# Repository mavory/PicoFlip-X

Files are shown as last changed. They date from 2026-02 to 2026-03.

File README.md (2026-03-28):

<div align="center">
  
# PicoFlip X 
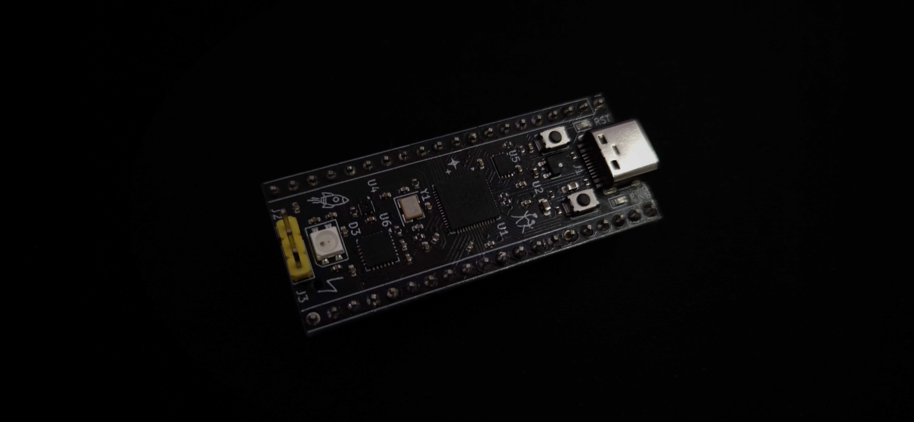
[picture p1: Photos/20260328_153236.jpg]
header


PicoFlip X is a compact RP2040 development board with a built-in IMU for motion tracking, there's also a humidity and temperature sensor! It has several status LEDs, buttons,...
</div>

## Key Features

- DevBoard powered by RP2040 chip
- Humidity and temperature sensor built right on the PCB
- 2 LEDs for visual feedback (PWR and RST)
- IMU - MPU 6050 to monitor the board's current position, all built-in
- USB-C connectivity
- 2-layer PCB, so it's cost-effective to manufacture!
- Modified GPIO pin layout and added one extra +3V3
- Custom silkscreen with images and descriptions

## Why I made this project?

When I finished my last project, I was thinking again about what I could do... I thought I'd try something hard and test my nerves... 💀
So I was looking and came up with this project - DEVBOARD!!

## Schema and PCB
  <div align="center">
    
Here is the circuit diagram!

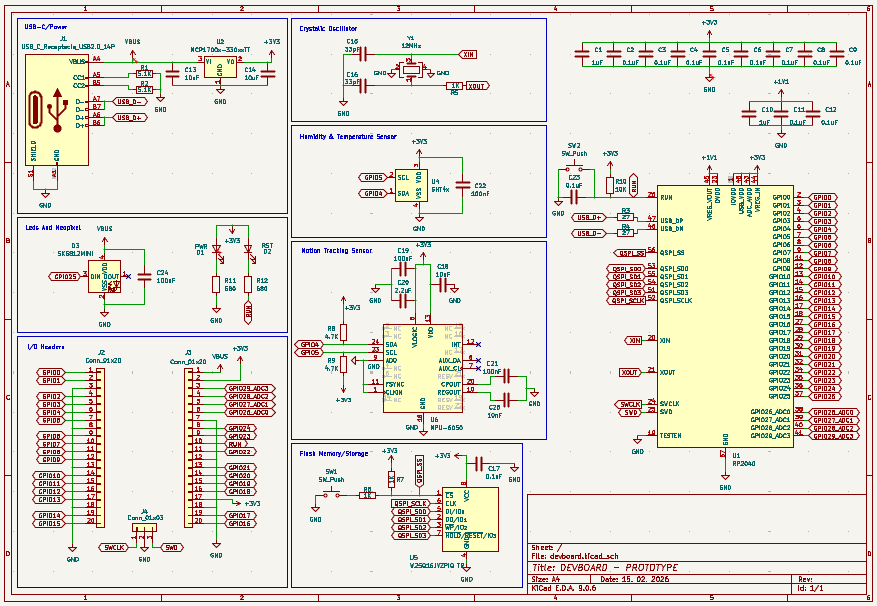
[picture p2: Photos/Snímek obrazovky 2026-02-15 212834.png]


Next, here is the PCB that is created in KiCad:
<div align="center">
  
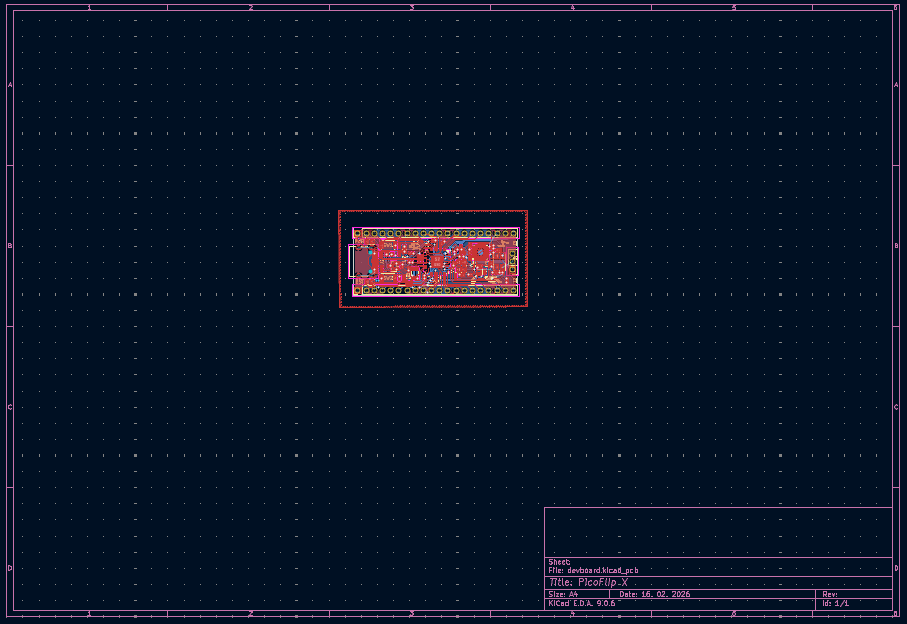
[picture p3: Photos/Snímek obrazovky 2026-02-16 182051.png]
PCB Design

  
</div></div>

## The Design :)
  <div align="center">
    
Here is the top side of the PCB:

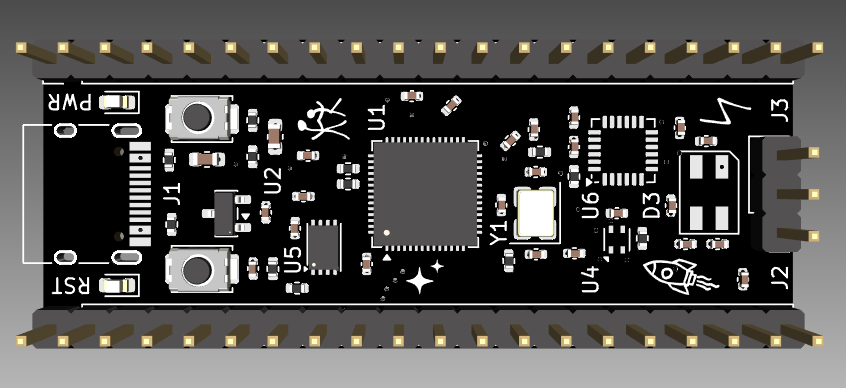
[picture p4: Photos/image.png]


Also here is the bottom of the PCB!
<div align="center">
  
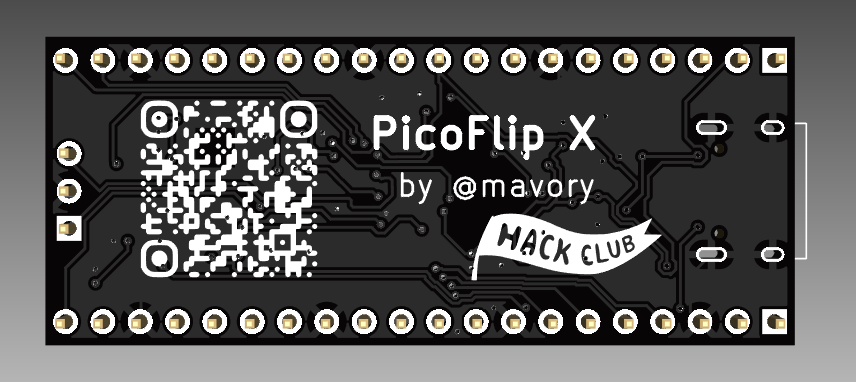
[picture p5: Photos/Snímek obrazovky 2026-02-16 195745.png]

  
</div></div>

## JLCPCB Order
<div align="center">
  
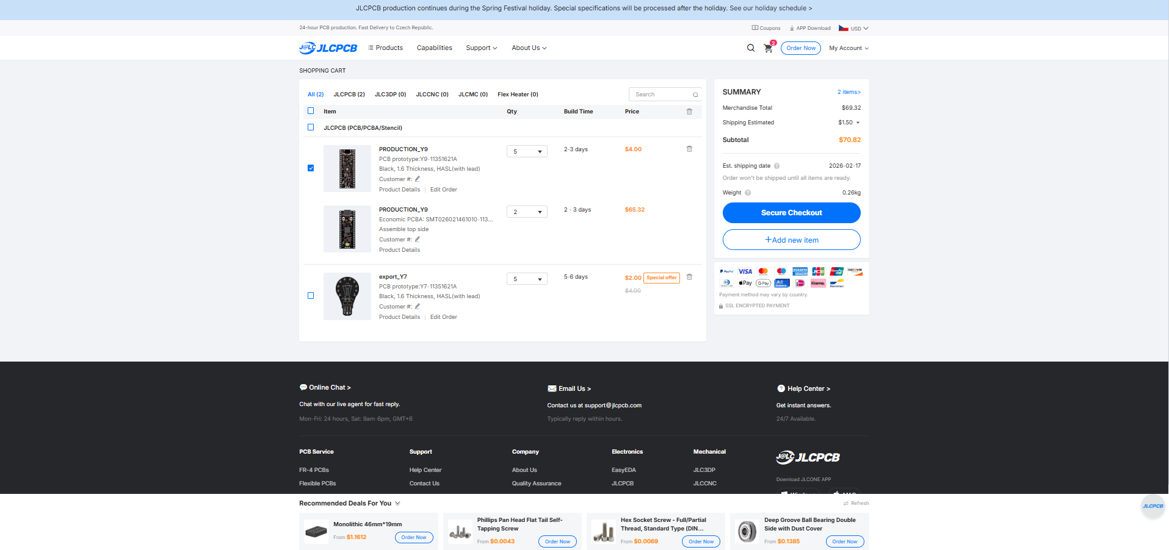
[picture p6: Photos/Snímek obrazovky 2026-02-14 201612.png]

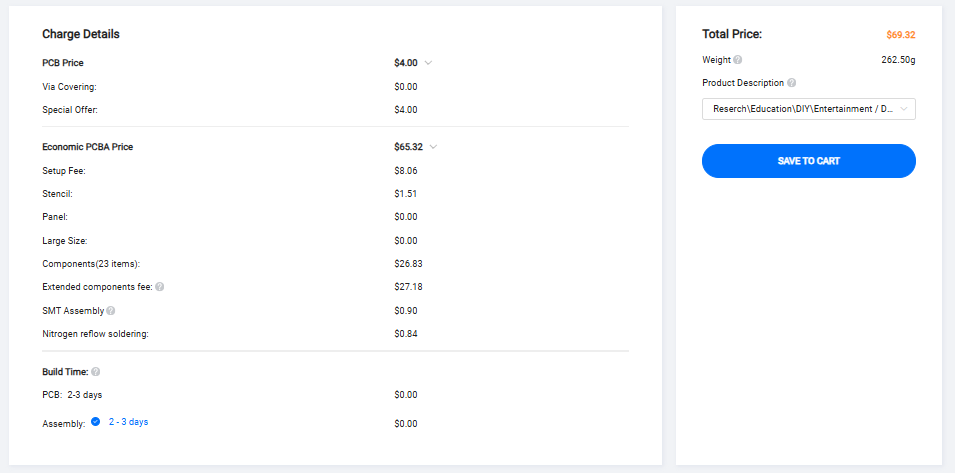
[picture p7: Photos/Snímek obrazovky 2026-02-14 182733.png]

  
</div>

## Bill of Materials

**Here is the complete BOM:**  

<details>
<summary>Click to expand!</summary>

| Top Designator | Comment | JLCPCB Part # | Product link | Lib Type | Qty | Source | Total Price ($) |
|---|---|---|---|---|---|---|---|
| C1,C10 | 1uF | C52923 | [Link](https://jlcpcb.com/partdetail/53938-CL05A105KA5NQNC/C52923) | Basic | 4 | 4 JLCPCB | 0,0132 |
| C2,C3,C4,C5,C6,C7,C8,C9,C11,C12,C17,C23 | 0.1uF | C1525 | [Link](https://jlcpcb.com/partdetail/1877-CL05B104KO5NNNC/C1525) | Basic | 32 | 32 JLCPCB | 0,0416 |
| C19,C21,C22,C24 | 100nF | ↑ | ↑ | ↑ | ↑ | ↑ | ↑ |
| C13,C14 | 10uF | C19702 | [Link](https://jlcpcb.com/partdetail/20411-CL10A106KP8NNNC/C19702) | Basic | 4 | 4 JLCPCB | 0,026 |
| C15,C16 | 33pF | C1562 | [Link](https://jlcpcb.com/partdetail/1914-0402CG330J500NT/C1562) | Basic | 4 | 4 JLCPCB | 0,0048 |
| C18,C25 | 10nF | C60133 | [Link](https://jlcpcb.com/partdetail/YAGEO-CC0402KRX7R9BB103/C60133) | Extended | 20 | 20 JLCPCB | 0,022 |
| C20 | 2.2uF | C12530 | [Link](https://jlcpcb.com/partdetail/13164-CL05A225MQ5NSNC/C12530) | Basic | 2 | 2 JLCPCB | 0,0052 |
| D3 | SK6812MINI | C7423117 | [Link](https://jlcpcb.com/partdetail/OPSCOOptoelectronics-SK6812MINIC/C7423117) | Extended | 5 | 5 JLCPCB | 0,428 |
| J1 | USB_C_Receptacle_USB2.0_14P | C165948 | [Link](https://jlcpcb.com/partdetail/Korean_HropartsElec-TYPE_C_31_M12/C165948) | Extended | 2 | 2 JLCPCB | 0,3624 |
| J2,J3 | Conn_01x20 | C50981 | [Link](https://jlcpcb.com/partdetail/51993-2_54_1_20P/C50981) | Extended | 4 | 4 JLCPCB | 0,4812 |
| J4 | Conn_01x03 | C49257 | [Link](https://jlcpcb.com/partdetail/50265-2_54_1_3P/C49257) | Extended | 4 | 4 JLCPCB | 0,0692 |
| PWR | POWER | C2286 | [Link](https://jlcpcb.com/partdetail/Hubei_KENTOElec-KT0603R/C2286) | Basic | 2 | 2 JLCPCB | 0,0128 |
| R1,R2 | 5.1K | C25905 | [Link](https://jlcpcb.com/partdetail/26648-0402WGF5101TCE/C25905) | Basic | 4 | 4 JLCPCB | 0,0032 |
| R3,R4 | 27 | C25100 | [Link](https://jlcpcb.com/partdetail/25843-0402WGF270JTCE/C25100) | Extended | 20 | 20 JLCPCB | 0,014 |
| R5,R6,R7 | 1K | C11702 | [Link](https://jlcpcb.com/partdetail/12256-0402WGF1001TCE/C11702) | Basic | 6 | 6 JLCPCB | 0,0042 |
| R8,R9 | 4.7K | C25900 | [Link](https://jlcpcb.com/partdetail/26643-0402WGF4701TCE/C25900) | Basic | 4 | 4 JLCPCB | 0,0032 |
| R10 | 10K | C25744 | [Link](https://jlcpcb.com/partdetail/26487-0402WGF1002TCE/C25744) | Basic | 2 | 2 JLCPCB | 0,0016 |
| R11,R12 | 680 | C25130 | [Link](https://jlcpcb.com/partdetail/25873-0402WGF6800TCE/C25130) | Extended | 20 | 20 JLCPCB | 0,016 |
| RST | RUN | C2288 | [Link](https://jlcpcb.com/partdetail/Hubei_KENTOElec-KT0603B/C2288) | Extended | 20 | 20 JLCPCB | 0,198 |
| SW1,SW2 | SW_Push | C720477 | [Link](https://jlcpcb.com/partdetail/XUNPU-TS_1088AR02016/C720477) | Basic | 4 | 4 JLCPCB | 0,1904 |
| U1 | RP2040 | C2040 | [Link](https://jlcpcb.com/partdetail/RaspberryPi-RP2040/C2040) | Extended | 2 | 2 JLCPCB | 1,9318 |
| U2 | MCP1700x-330xxTT | C39051 | [Link](https://jlcpcb.com/partdetail/MicrochipTech-MCP1700T_3302ETT/C39051) | Extended | 5 | 5 JLCPCB | 1,807 |
| U4 | SHT4x | C2848306 | [Link](https://jlcpcb.com/partdetail/Sensirion-SHT40_AD1BR3/C2848306) | Extended | 2 | 2 JLCPCB | 3,427 |
| U5 | W25Q16JVZPIQTR | C2843335 | [Link](https://jlcpcb.com/partdetail/WinbondElec-W25Q16JVUXIQ/C2843335) | Extended | 2 | 2 JLCPCB | 2,3964 |
| U6 | MPU-6050 | C24112 | [Link](https://jlcpcb.com/partdetail/TDKInvenSense-MPU6050/C24112) | Extended | 2 | 2 JLCPCB | 15,7754 |
| Y1 | 12MHz | C9002 | [Link](https://jlcpcb.com/partdetail/YXC_CrystalOscillators-X322512MSB4SI/C9002) | Basic | 2 | 2 JLCPCB | 0,1452 |
| PCBA (Parts + Assembly) |  |  |  |  |  |  | 65,32 |
| PCB (Black) |  |  |  |  |  |  | 4 |
| Shipping (GSDL) |  |  |  |  |  |  | 1,5 |
| TOTAL |  |  |  |  |  |  | 70,82 |

The bill of material is also available here: [BOM.csv](https://github.com/mavory/PicoFlip-X/blob/bba36edf56afa61a020f22f13432fc22c765aea1/BOM.csv)

</details>

<hr>
<div align="center">

Here is the link to the video: [YouTube](https://youtu.be/9DEOVKMEVFU)

<hr>

Made with ❤️ - by [@mavory](https://github.com/mavory) | Also thank you for providing the guide [@Kai Pereira](https://github.com/kaipereira)!

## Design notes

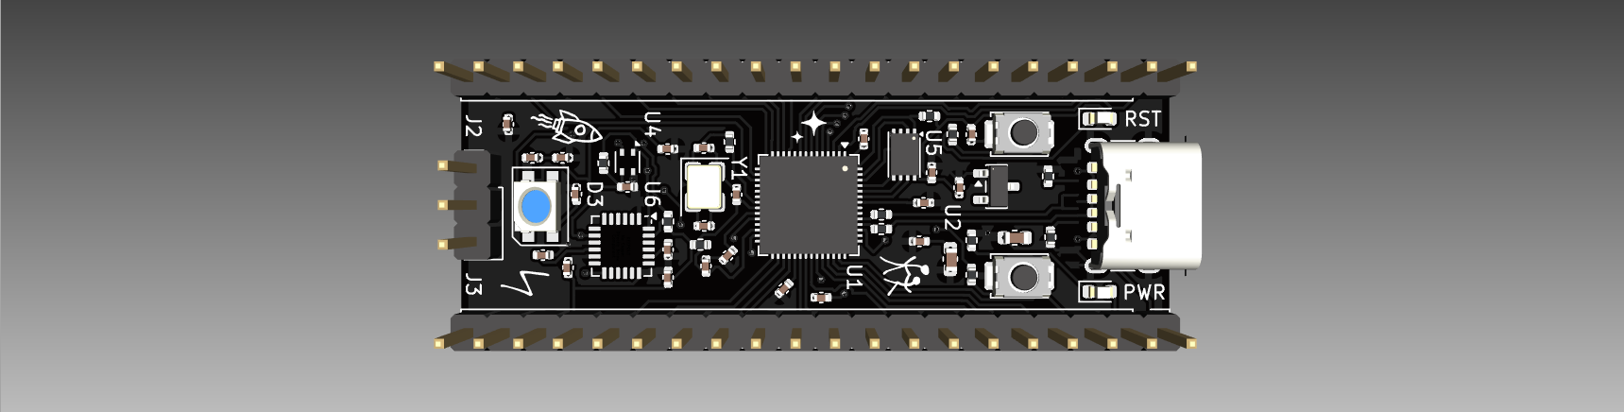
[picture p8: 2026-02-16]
Photos/Snímek obrazovky 2026-02-14 212531.png

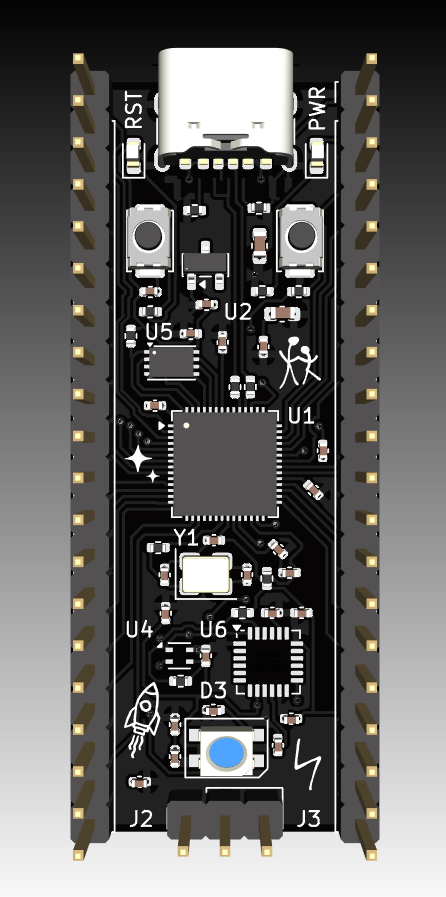
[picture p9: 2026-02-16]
Photos/Snímek obrazovky 2026-02-14 212512.png

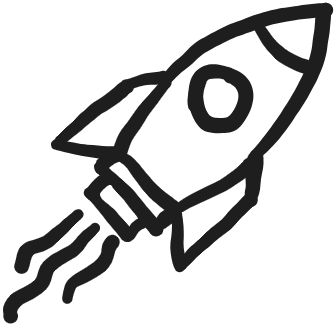
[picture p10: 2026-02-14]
Photos/rocket.png

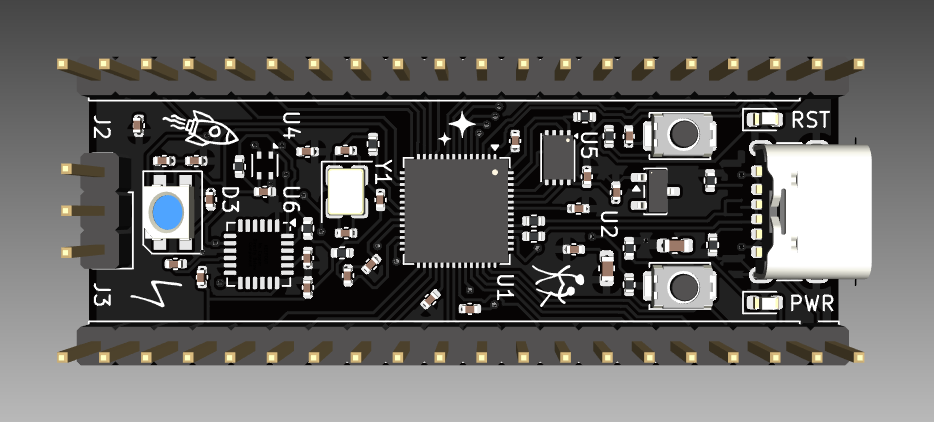
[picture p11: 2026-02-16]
Photos/Snímek obrazovky 2026-02-14 212539.png

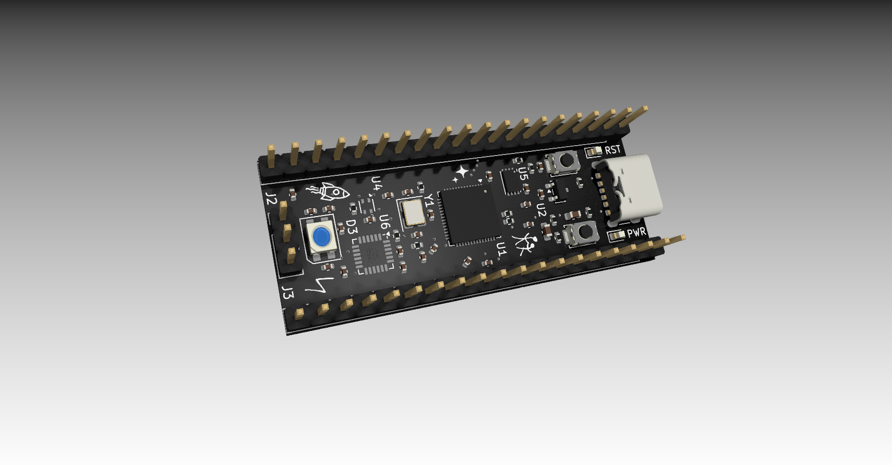
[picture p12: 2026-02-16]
Photos/Snímek obrazovky 2026-02-14 212742.png

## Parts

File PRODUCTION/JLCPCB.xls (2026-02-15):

JLCPCB BOM Tool - BOM Matching
BOM name：BOM-JLCPCB Assembly Order.xlsx |  |  | Download Time：2026-02-15 01:15:31 |  |  |  | * Our matching results are updated in real-time, but stock and prices may change. If it's been over 24 hours, please re-match before placing your order.
PCB Assembled Qty：5 |  |  | Est. Total Price：27.4214
Your BOM |  |  |  |  | Matched Parts |  |  |  |  |  |  | Order Information
Top Designator | Bottom Designator | Comment | Footprint | JLCPCB Part # | Matches | Part # | Manufacturer | Footprint | Description | Category | Warning | JLCPCB Part # | Product link | Lib Type | Qty | Source | Total Price ($)
C1,C10 |  | 1uF | Capacitor_SMD:C_0402_1005Metric |  | Select by Customer | CL05A105KA5NQNC | Samsung Electro-Mechanics | 0402 | 1uF 25V X5R ±10% 0402 Multilayer Ceramic Capacitors MLCC - SMD/SMT ROHS | Multilayer Ceramic Capacitors MLCC - SMD/SMT |  | C52923 | https://jlcpcb.com/partdetail/53938-CL05A105KA5NQNC/C52923 | Basic | 4 | 4 JLCPCB | 0.0132
C2,C3,C4,C5,C6,C7,C8,C9,C11,C12,C17,C23 |  | 0.1uF | Capacitor_SMD:C_0402_1005Metric |  | Select by Customer | CL05B104KO5NNNC | Samsung Electro-Mechanics | 0402 | 100nF 16V X7R ±10% 0402 Multilayer Ceramic Capacitors MLCC - SMD/SMT ROHS | Multilayer Ceramic Capacitors MLCC - SMD/SMT | 1.The comment (CL05B104KO5NNNC) of this part does not match the one (0.1uF) provided in your BOM. Please confirm; 2.Multiple lines in the BOM have been matched to the same part. Please check if the matching is correct. ; | C1525 | https://jlcpcb.com/partdetail/1877-CL05B104KO5NNNC/C1525 | Basic | 32 | 32 JLCPCB | 0.0416
C19,C21,C22,C24 |  | 100nF | Capacitor_SMD:C_0402_1005Metric |  | Select by Customer | CL05B104KO5NNNC | Samsung Electro-Mechanics | 0402 | 100nF 16V X7R ±10% 0402 Multilayer Ceramic Capacitors MLCC - SMD/SMT ROHS | Multilayer Ceramic Capacitors MLCC - SMD/SMT | 1.Multiple lines in the BOM have been matched to the same part. Please check if the matching is correct. ; | C1525 | https://jlcpcb.com/partdetail/1877-CL05B104KO5NNNC/C1525 | Basic | 32 | 32 JLCPCB | 0.0416
C13,C14 |  | 10uF | Capacitor_SMD:C_0603_1608Metric |  | Select by Customer | CL10A106KP8NNNC | Samsung Electro-Mechanics | 0603 | 10V 10uF X5R ±10% 0603 Multilayer Ceramic Capacitors MLCC - SMD/SMT ROHS | Multilayer Ceramic Capacitors MLCC - SMD/SMT |  | C19702 | https://jlcpcb.com/partdetail/20411-CL10A106KP8NNNC/C19702 | Basic | 4 | 4 JLCPCB | 0.026
C15,C16 |  | 33pF | Capacitor_SMD:C_0402_1005Metric |  | Select by Customer | 0402CG330J500NT | FH (Guangdong Fenghua Advanced Tech) | 0402 | 33pF 50V C0G ±5% 0402 Multilayer Ceramic Capacitors MLCC - SMD/SMT ROHS | Multilayer Ceramic Capacitors MLCC - SMD/SMT |  | C1562 | https://jlcpcb.com/partdetail/1914-0402CG330J500NT/C1562 | Basic | 4 | 4 JLCPCB | 0.0048
C18,C25 |  | 10nF | Capacitor_SMD:C_0402_1005Metric |  | Select by Customer | CC0402KRX7R9BB103 | YAGEO | 0402 | 10nF 50V X7R ±10% 0402 Multilayer Ceramic Capacitors MLCC - SMD/SMT ROHS | Multilayer Ceramic Capacitors MLCC - SMD/SMT |  | C60133 | https://jlcpcb.com/partdetail/YAGEO-CC0402KRX7R9BB103/C60133 | Extended | 20 | 20 JLCPCB | 0.022
C20 |  | 2.2uF | Capacitor_SMD:C_0402_1005Metric |  | Select by Customer | CL05A225MQ5NSNC | Samsung Electro-Mechanics | 0402 | 2.2uF 6.3V X5R ±20% 0402 Multilayer Ceramic Capacitors MLCC - SMD/SMT ROHS | Multilayer Ceramic Capacitors MLCC - SMD/SMT |  | C12530 | https://jlcpcb.com/partdetail/13164-CL05A225MQ5NSNC/C12530 | Basic | 2 | 2 JLCPCB | 0.0052
D3 |  | SK6812MINI | LED_SMD:LED_SK6812MINI_PLCC4_3.5x3.5mm_P1.75mm |  | Select by Customer | SK6812MINI-C | OPSCO Optoelectronics | SMD-4P,3.7x3.5mm | -40℃~+85℃ 0.65mA 1.1mm 120° 1kHz 2000V 3.5mm 3.7V~5.5V 3.7mm G:520nm~530nm、B:460nm~470nm、R:615nm~625nm G:815mcd~1275mcd、B:160mcd~320mcd、R:280mcd~515mcd SMD-4P,3.7x3.5mm RGB LEDs(Built-in IC) ROHS | RGB LEDs(Built-In IC) | 1.The comment (SK6812MINI-C) of this part does not match the one (SK6812MINI) provided in your BOM. Please confirm; | C7423117 | https://jlcpcb.com/partdetail/OPSCOOptoelectronics-SK6812MINIC/C7423117 | Extended | 5 | 5 JLCPCB | 0.428
J1 |  | USB_C_Receptacle_USB2.0_14P | Connector_USB:USB_C_Receptacle_HRO_TYPE-C-31-M-12 |  | Select by Customer | TYPE-C-31-M-12 | Korean Hroparts Elec | SMD | -30℃~+80℃ 1 10,000 cycles 16P 20V 5A 7.35mm Female Surface Mount, Right Angle Type-C SMD USB Connectors ROHS | USB Connectors |  | C165948 | https://jlcpcb.com/partdetail/Korean_HropartsElec-TYPE_C_31_M12/C165948 | Extended | 2 | 2 JLCPCB | 0.3624
J2,J3 |  | Conn_01x20 | Connector_PinHeader_2.54mm:PinHeader_1x20_P2.54mm_Vertical |  | Select by Customer | 2.54-1*20P直针 | BOOMELE(Boom Precision Elec) | 插件,P=2.54mm | -40℃~+105℃ 1 1x20P 2.54mm 20P 3A Black Brass Pin Header Through Hole Plugin,P=2.54mm Pin Headers ROHS | Pin Headers |  | C50981 | https://jlcpcb.com/partdetail/51993-2_54_1_20P/C50981 | Extended | 4 | 4 JLCPCB | 0.4812
J4 |  | Conn_01x03 | Connector_PinHeader_2.54mm:PinHeader_1x03_P2.54mm_Vertical |  | Select by Customer | 2.54-1*3P针 | BOOMELE(Boom Precision Elec) | 插件,P=2.54mm | -40℃~+105℃ 1 1x3P 2.54mm 2.5mm 3A 3P 3mm 6mm Black Brass Gold Pin Header Through Hole Plugin,P=2.54mm Pin Headers ROHS | Pin Headers |  | C49257 | https://jlcpcb.com/partdetail/50265-2_54_1_3P/C49257 | Extended | 4 | 4 JLCPCB | 0.0692
PWR |  | POWER | LED_SMD:LED_0603_1608Metric |  | Select by Customer | KT-0603R | Hubei KENTO Elec | 0603 | -40℃~+85℃ 120° 2.4V 20mA 300mcd 40mW 615nm~630nm 645nm Discrete Diode Red Water Clear 0603 LED Indication - Discrete ROHS | LED Indication - Discrete | 1.The comment (KT-0603R) of this part does not match the one (POWER) provided in your BOM. Please confirm; | C2286 | https://jlcpcb.com/partdetail/Hubei_KENTOElec-KT0603R/C2286 | Basic | 2 | 2 JLCPCB | 0.0128
R1,R2 |  | 5.1K | Resistor_SMD:R_0402_1005Metric |  | Select by Customer | 0402WGF5101TCE | UNI-ROYAL(Uniroyal Elec) | 0402 | -55℃~+155℃ 5.1kΩ 50V 62.5mW Thick Film Resistor ±1% ±100ppm/℃ 0402 Chip Resistor - Surface Mount ROHS | Chip Resistor - Surface Mount |  | C25905 | https://jlcpcb.com/partdetail/26648-0402WGF5101TCE/C25905 | Basic | 4 | 4 JLCPCB | 0.0032
R3,R4 |  | 27 | Resistor_SMD:R_0402_1005Metric |  | Select by Customer | 0402WGF270JTCE | UNI-ROYAL(Uniroyal Elec) | 0402 | -55℃~+155℃ 27Ω 50V 62.5mW Thick Film Resistor ±1% ±100ppm/℃ 0402 Chip Resistor - Surface Mount ROHS | Chip Resistor - Surface Mount | 1.The comment (0402WGF270JTCE) of this part does not match the one (27) provided in your BOM. Please confirm; | C25100 | https://jlcpcb.com/partdetail/25843-0402WGF270JTCE/C25100 | Extended | 20 | 20 JLCPCB | 0.014
R5,R6,R7 |  | 1K | Resistor_SMD:R_0402_1005Metric |  | Select by Customer | 0402WGF1001TCE | UNI-ROYAL(Uniroyal Elec) | 0402 | -55℃~+155℃ 1kΩ 50V 62.5mW Thick Film Resistor ±1% ±100ppm/℃ 0402 Chip Resistor - Surface Mount ROHS | Chip Resistor - Surface Mount | 1.The comment (0402WGF1001TCE) of this part does not match the one (1K) provided in your BOM. Please confirm; | C11702 | https://jlcpcb.com/partdetail/12256-0402WGF1001TCE/C11702 | Basic | 6 | 6 JLCPCB | 0.0042
R8,R9 |  | 4.7K | Resistor_SMD:R_0402_1005Metric |  | Select by Customer | 0402WGF4701TCE | UNI-ROYAL(Uniroyal Elec) | 0402 | -55℃~+155℃ 4.7kΩ 50V 62.5mW Thick Film Resistor ±1% ±100ppm/℃ 0402 Chip Resistor - Surface Mount ROHS | Chip Resistor - Surface Mount | 1.The comment (0402WGF4701TCE) of this part does not match the one (4.7K) provided in your BOM. Please confirm; | C25900 | https://jlcpcb.com/partdetail/26643-0402WGF4701TCE/C25900 | Basic | 4 | 4 JLCPCB | 0.0032
R10 |  | 10K | Resistor_SMD:R_0402_1005Metric |  | Select by Customer | 0402WGF1002TCE | UNI-ROYAL(Uniroyal Elec) | 0402 | -55℃~+155℃ 10kΩ 50V 62.5mW Thick Film Resistor ±1% ±100ppm/℃ 0402 Chip Resistor - Surface Mount ROHS | Chip Resistor - Surface Mount | 1.The comment (0402WGF1002TCE) of this part does not match the one (10K) provided in your BOM. Please confirm; | C25744 | https://jlcpcb.com/partdetail/26487-0402WGF1002TCE/C25744 | Basic | 2 | 2 JLCPCB | 0.0016
R11,R12 |  | 680 | Resistor_SMD:R_0402_1005Metric |  | Select by Customer | 0402WGF6800TCE | UNI-ROYAL(Uniroyal Elec) | 0402 | -55℃~+155℃ 50V 62.5mW 680Ω Thick Film Resistor ±1% ±100ppm/℃ 0402 Chip Resistor - Surface Mount ROHS | Chip Resistor - Surface Mount | 1.The comment (0402WGF6800TCE) of this part does not match the one (680) provided in your BOM. Please confirm; | C25130 | https://jlcpcb.com/partdetail/25873-0402WGF6800TCE/C25130 | Extended | 20 | 20 JLCPCB | 0.016
RST |  | RUN | LED_SMD:LED_0603_1608Metric |  | Select by Customer | KT-0603B | Hubei KENTO Elec | 0603 | 100mW 120° 175mcd 3.1V 460nm~475nm 469nm 5mA Blue Discrete Diode Water Clear 0603 LED Indication - Discrete ROHS | LED Indication - Discrete |  | C2288 | https://jlcpcb.com/partdetail/Hubei_KENTOElec-KT0603B/C2288 | Extended | 20 | 20 JLCPCB | 0.198
SW1,SW2 |  | SW_Push | Button_Switch_SMD:SW_Push_SPST_NO_Alps_SKRK |  | Select by Customer | TS-1088-AR02016 | XUNPU | SMD,4x3mm | -30℃~+80℃ 1.6N 100,000 Cycles 12V 2mm 3mm 4mm 50mA Black Round Button SMD(SMT) Tab SPST Surface Mount,Vertical Without Bracket SMD,4x3mm Tactile Switches ROHS | Tactile Switches |  | C720477 | https://jlcpcb.com/partdetail/XUNPU-TS_1088AR02016/C720477 | Basic | 4 | 4 JLCPCB | 0.1904
U1 |  | RP2040 | Package_DFN_QFN:QFN-56-1EP_7x7mm_P0.4mm_EP3.2x3.2mm |  | Select by Customer | RP2040 | Raspberry Pi | LQFN-56(7x7) | 12bit 133MHz 30 LQFN-56(7x7) Microcontrollers (MCU/MPU/SOC) ROHS | Microcontrollers (MCU/MPU/SOC) |  | C2040 | https://jlcpcb.com/partdetail/RaspberryPi-RP2040/C2040 | Extended | 2 | 2 JLCPCB | 1.9318
U2 |  | MCP1700x-330xxTT | Package_TO_SOT_SMD:SOT-23 |  | Select by Customer | MCP1700T-3302E/TT | Microchip Tech | SOT-23 | -40℃~+125℃@(Tj) 1 1.6uA 178mV@(250mA) 250mA 3.3V 44dB@(100Hz) 6V Fixed Over Temperature Protection、Short Circuit Protection Positive SOT-23 Voltage Regulators - Linear, Low Drop Out (LDO) Regulators ROHS | Voltage Regulators - Linear, Low Drop Out (LDO) Regulators |  | C39051 | https://jlcpcb.com/partdetail/MicrochipTech-MCP1700T_3302ETT/C39051 | Extended | 5 | 5 JLCPCB | 1.807
U4 |  | SHT4x | Sensor_Humidity:Sensirion_DFN-4_1.5x1.5mm_P0.8mm_SHT4x_NoCentralPad |  | Select by Customer | SHT40-AD1B-R3 | Sensirion | DFN-4-EP(1.5x1.5) | -40℃~+125℃ 0%RH~100%RH 1.08V~3.6V 16bit 400nA I2C ±0.2℃ ±1.8%RH DFN-4-EP(1.5x1.5) Temperature and Humidity Sensor ROHS | Global Sourcing Parts |  | C2848306 | https://jlcpcb.com/partdetail/Sensirion-SHT40_AD1BR3/C2848306 | Extended | 2 | 2 JLCPCB | 3.427
U5 |  | W25Q16JVZPIQTR | Package_SON:Winbond_USON-8-1EP_3x2mm_P0.5mm_EP0.2x1.6mm |  | Select by Customer | W25Q16JVUXIQ | Winbond Elec | USON-8-EP(2x3) | -40℃~+85℃ 100,000 Cycles 10uA 133MHz 16Mbit 2.7V~3.6V 20 Years 3ms SPI USON-8-EP(2x3) NOR FLASH ROHS | NOR FLASH | 1.The comment (W25Q16JVUXIQ) of this part does not match the one (W25Q16JVZPIQTR) provided in your BOM. Please confirm; | C2843335 | https://jlcpcb.com/partdetail/WinbondElec-W25Q16JVUXIQ/C2843335 | Extended | 2 | 2 JLCPCB | 2.3964
U6 |  | MPU-6050 | Sensor_Motion:InvenSense_QFN-24_4x4mm_P0.5mm |  | Select by Customer | MPU-6050 | TDK InvenSense | QFN-24-EP(4x4) | -40℃~+85℃ 16bit 1KB 2.375V~3.46V 5uA Accelerometer Gyroscope I2C X,Y,Z X,Y,Z ±16g ±2000dps QFN-24-EP(4x4) Accelerometers ROHS | Accelerometers |  | C24112 | https://jlcpcb.com/partdetail/TDKInvenSense-MPU6050/C24112 | Extended | 2 | 2 JLCPCB | 15.7754
Y1 |  | 12MHz | Crystal:Crystal_SMD_3225-4Pin_3.2x2.5mm |  | Select by Customer | X322512MSB4SI | YXC Crystal Oscillators | SMD3225-4P | -40℃~+85℃ 12MHz 20pF Crystal Oscillator ±10ppm ±20ppm SMD3225-4P Crystals ROHS | Crystals |  | C9002 | https://jlcpcb.com/partdetail/YXC_CrystalOscillators-X322512MSB4SI/C9002 | Basic | 2 | 2 JLCPCB | 0.1452

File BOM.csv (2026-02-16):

Top Designator | Comment | JLCPCB Part # | Product link | Lib Type | Qty | Source | Total Price ($)
C1,C10 | 1uF | C52923 | https://jlcpcb.com/partdetail/53938-CL05A105KA5NQNC/C52923 | Basic | 4 | 4 JLCPCB | 0,0132
C2,C3,C4,C5,C6,C7,C8,C9,C11,C12,C17,C23 | 0.1uF | C1525 | https://jlcpcb.com/partdetail/1877-CL05B104KO5NNNC/C1525 | Basic | 32 | 32 JLCPCB | 0,0416
C19,C21,C22,C24 | 100nF
C13,C14 | 10uF | C19702 | https://jlcpcb.com/partdetail/20411-CL10A106KP8NNNC/C19702 | Basic | 4 | 4 JLCPCB | 0,026
C15,C16 | 33pF | C1562 | https://jlcpcb.com/partdetail/1914-0402CG330J500NT/C1562 | Basic | 4 | 4 JLCPCB | 0,0048
C18,C25 | 10nF | C60133 | https://jlcpcb.com/partdetail/YAGEO-CC0402KRX7R9BB103/C60133 | Extended | 20 | 20 JLCPCB | 0,022
C20 | 2.2uF | C12530 | https://jlcpcb.com/partdetail/13164-CL05A225MQ5NSNC/C12530 | Basic | 2 | 2 JLCPCB | 0,0052
D3 | SK6812MINI | C7423117 | https://jlcpcb.com/partdetail/OPSCOOptoelectronics-SK6812MINIC/C7423117 | Extended | 5 | 5 JLCPCB | 0,428
J1 | USB_C_Receptacle_USB2.0_14P | C165948 | https://jlcpcb.com/partdetail/Korean_HropartsElec-TYPE_C_31_M12/C165948 | Extended | 2 | 2 JLCPCB | 0,3624
J2,J3 | Conn_01x20 | C50981 | https://jlcpcb.com/partdetail/51993-2_54_1_20P/C50981 | Extended | 4 | 4 JLCPCB | 0,4812
J4 | Conn_01x03 | C49257 | https://jlcpcb.com/partdetail/50265-2_54_1_3P/C49257 | Extended | 4 | 4 JLCPCB | 0,0692
PWR | POWER | C2286 | https://jlcpcb.com/partdetail/Hubei_KENTOElec-KT0603R/C2286 | Basic | 2 | 2 JLCPCB | 0,0128
R1,R2 | 5.1K | C25905 | https://jlcpcb.com/partdetail/26648-0402WGF5101TCE/C25905 | Basic | 4 | 4 JLCPCB | 0,0032
R3,R4 | 27 | C25100 | https://jlcpcb.com/partdetail/25843-0402WGF270JTCE/C25100 | Extended | 20 | 20 JLCPCB | 0,014
R5,R6,R7 | 1K | C11702 | https://jlcpcb.com/partdetail/12256-0402WGF1001TCE/C11702 | Basic | 6 | 6 JLCPCB | 0,0042
R8,R9 | 4.7K | C25900 | https://jlcpcb.com/partdetail/26643-0402WGF4701TCE/C25900 | Basic | 4 | 4 JLCPCB | 0,0032
R10 | 10K | C25744 | https://jlcpcb.com/partdetail/26487-0402WGF1002TCE/C25744 | Basic | 2 | 2 JLCPCB | 0,0016
R11,R12 | 680 | C25130 | https://jlcpcb.com/partdetail/25873-0402WGF6800TCE/C25130 | Extended | 20 | 20 JLCPCB | 0,016
RST | RUN | C2288 | https://jlcpcb.com/partdetail/Hubei_KENTOElec-KT0603B/C2288 | Extended | 20 | 20 JLCPCB | 0,198
SW1,SW2 | SW_Push | C720477 | https://jlcpcb.com/partdetail/XUNPU-TS_1088AR02016/C720477 | Basic | 4 | 4 JLCPCB | 0,1904
U1 | RP2040 | C2040 | https://jlcpcb.com/partdetail/RaspberryPi-RP2040/C2040 | Extended | 2 | 2 JLCPCB | 1,9318
U2 | MCP1700x-330xxTT | C39051 | https://jlcpcb.com/partdetail/MicrochipTech-MCP1700T_3302ETT/C39051 | Extended | 5 | 5 JLCPCB | 1,807
U4 | SHT4x | C2848306 | https://jlcpcb.com/partdetail/Sensirion-SHT40_AD1BR3/C2848306 | Extended | 2 | 2 JLCPCB | 3,427
U5 | W25Q16JVZPIQTR | C2843335 | https://jlcpcb.com/partdetail/WinbondElec-W25Q16JVUXIQ/C2843335 | Extended | 2 | 2 JLCPCB | 2,3964
U6 | MPU-6050 | C24112 | https://jlcpcb.com/partdetail/TDKInvenSense-MPU6050/C24112 | Extended | 2 | 2 JLCPCB | 15,7754
Y1 | 12MHz | C9002 | https://jlcpcb.com/partdetail/YXC_CrystalOscillators-X322512MSB4SI/C9002 | Basic | 2 | 2 JLCPCB | 0,1452
PCBA (Parts + Assembly) |  |  |  |  |  |  | 65,32
PCB (Black) |  |  |  |  |  |  | 4
Shipping (GSDL) |  |  |  |  |  |  | 1,5
TOTAL |  |  |  |  |  |  | 70,82

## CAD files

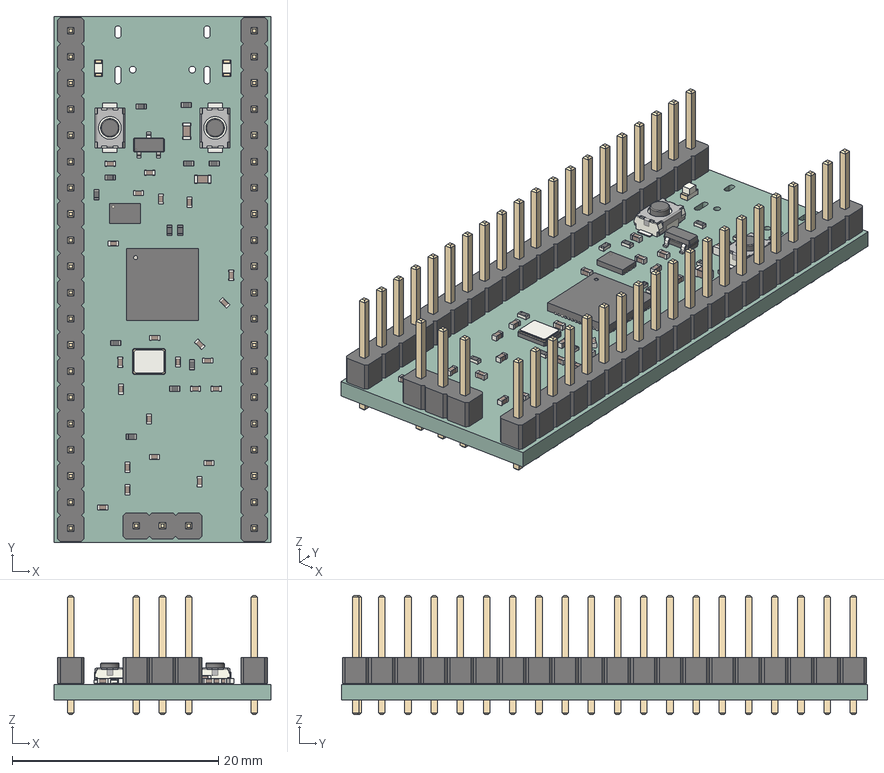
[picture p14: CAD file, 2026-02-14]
PCB/3D model.step
21.0 x 51.0 x 11.5 mm
C_0402_1005Metric x 23
R_0402_1005Metric x 12
C_0603_1608Metric x 2
Winbond_USON-8-1EP_3x2mm_P0.5mm_EP0.2x1.6mm
Crystal_SMD_3225-4Pin_3.2x2.5mm
SW_Push_SPST_NO_Alps_SKRK x 2
PinHeader_1x20_P2.54mm_Vertical x 2
LED_0603_1608Metric x 2
PinHeader_1x03_P2.54mm_Vertical
QFN-56-1EP_7x7mm_P0.4mm_EP3.2x3.2mm
SOT-23
devboard_PCB

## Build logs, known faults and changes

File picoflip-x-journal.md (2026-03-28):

2/14/2026 9 PM - The beginning of my project!!
Time spent: 2.1h
When I finished my last project, I was thinking again about what I could do... I thought I'd try something hard and test my nerves... 💀
So I was looking and came up with this project - DEVBOARD!! I started to gradually make and create a diagram. When I had most of it done, I needed something to make my DevBoard special, to make it unique!
I stopped thinking and went to do something. I opened KiCad and started inserting all the components and connecting them according to the instructions. It went pretty well, but I got stuck on a few things for a while because I had never encountered them before.

Snímek obrazovky 2026-02-09 183541

2/14/2026 10:01 PM - Adding custom components
Time spent: 1.8h
I kept adding more and more things and I was slowly getting it done. But then I remembered that I wanted to add something! I decided to go for the ICM-20602 and SHT4x first.

Snímek obrazovky 2026-02-10 201901

So I put them in the program and started researching how to connect it... I've never worked with them before, so that was probably the hardest part for me so far. I also had to do some research on how these things are connected and I decided to connect the ICM via I2C!! I gradually started adding resistors and other things and after a long time I had it connected with all the things :)

Snímek obrazovky 2026-02-10 204240

2/14/2026 10:12 PM - Schema editing
Time spent: 1.4h
Right after adding the sensors I thought I would like to add 2 LEDs for indication and 1 neopixel that would be programmable via GPIO25! So I was looking for some components to make them small but powerful.
I decided on WS2818B-2020 and normal SMD LEDs. I immediately prepared them and added them to the work surface. But I thought for a while how I could use the LEDs and what they would indicate. I told myself that it would be best if I chose this:
1st LED - POWER indicator
2nd LED - RESET indicator
So I started looking again how to connect them and it went pretty quickly, so I had time to redo a few things.

Snímek obrazovky 2026-02-11 172207

2/14/2026 10:19 PM - Pin assignment
Time spent: 0.6h
I was thinking about how I would make the pins on my DevBoard... So I started experimenting and at first the pins didn't fit at all, so I started redoing it and said to myself that I'd better add another 3v3 on one side for some reason, because as I know myself, it will definitely come in handy in the future :)
So I already arranged the pins well and where there was space left, I put GND.

Snímek obrazovky 2026-02-11 185952

2/14/2026 10:29 PM - Editing a KiCad project
Time spent: 1.7h
Before I start assigning cases, I made parts of all the things so that I can understand them later and read the schematic better when, for example, I make a PCB.
I didn't know where to do it at all, so I had to look up where to make the border and then I found out that it's normally a rectangle... 🧑‍🦽
So it went pretty quickly, but I had to play around with it to get everything to fit so well.

Snímek obrazovky 2026-02-11 194257

Assigning cases
As I wrote earlier, I started working on the cases. First, I marked all the same capacitors and gradually assigned them. I did the same with other things. It was the kind of thing that I didn't enjoy at all, but I had to do it anyway so that it would work well later.

Snímek obrazovky 2026-02-11 203945

2/14/2026 10:40 PM - Getting started with PCB design!
Time spent: 3.6h
After checking everything to make sure I wasn't missing anything, I ran the rules check test again and there were no errors that would jeopardize my project. So I could move on to the PCB itself.
I imported all the stuff and started connecting everything. I told myself several times that I would never be able to do it and that it would be terrible (it happened).
But I continued with the connections, which was really difficult for me.
Several times I had to delete several paths so that I could run another important wire and then re-draw the ones I had deleted. Well... it was very difficult, but I don't know how I managed to do it. I think I could do it even better next time, but for my first PCB that is difficult for me, I'm glad I connected everything at all.

Snímek obrazovky 2026-02-13 151409

2/14/2026 10:51 PM - Error correction
Time spent: 1.2h
I didn't think it would be error-free at all, so I immediately opened DRC and started redoing things that were badly connected, somewhere it touched the connections of some components to each other, but I solved that.

Snímek obrazovky 2026-02-13 151652

Unfortunately, ICM-20602 was still annoying me and I didn't know why... So I did some research and found out that I had to modify KiCad so that it wouldn't be so strict with this component. So I modified it and then all that was left was to pour the board, with copper.

Snímek obrazovky 2026-02-13 153254

2/15/2026 4:19 PM - Silkscreen creation
Time spent: 0.9h
When I was sure I could continue, I decided to go straight to silkscreen.
I created all the necessary things like:
A QR code that has the URL to my GitHub project
A name I chose "PicoFlip X" or PFX for short
I also added my nickname at the bottom
On the top I put my own images that I created and I wanted some smaller images:

Snímek obrazovky 2026-02-13 215404

Silkscreen editing
So I continued importing the images and I also had to resize them somehow, so that took me a while. Then I had to put them on the PCB and play around with the layout and here is the bottom:

Snímek obrazovky 2026-02-13 221942

2/15/2026 4:44 PM - JLCPCB wants a lot of money from me...
Time spent: 0.7h
I started making tables and all the exports for the production of the JLCPCB board and when I was making tables, it was still quite good... Then I compressed all the files into a .ZIP file and uploaded it to the site. What I was afraid of came - they wanted me to choose a PCBA standard, because components like neopixel, ICM were only installed in the standard.
So I came across this huge problem of mine and said to myself that I would redo it rather than submit with about 100 dollars.

Snímek obrazovky 2026-02-13 233512

2/15/2026 10:20 PM - Schema reworking
Time spent: 1.0h
So I had to choose some better components and I decided as follows:
Instead of ICM I will use MPU 6050
Instead of WS2812B I will use SK6812.
So I found the parts in KiCad and started to modify... But I still had to check if JLCPCB really assembles it in economic PCBA - and it does, so I could celebrate!!!

sn__mek_obrazovky_2026-02-14_133024

2/15/2026 10:28 PM - PCB editing
Time spent: 1.6h
So I started connecting all the components together and it went pretty well, except for a few things where I had to think a little more.
Next I poured copper all over the board, but in some places the copper didn't pour properly, so I had to connect the components manually. This was more difficult for me, but I managed it.
So I continued with silkscreen, because in some places the components were placed differently and would interfere with it. I also rewrote the LEDs so that in the future I would know what each of them indicates.



2/15/2026 10:51 PM - JLCPCB
Time spent: 1.9h
Right after everything I decided to export and create a spreadsheet for JLCPCB. First I had to remember where everything was and save it all in one folder. Then I continued with the production files, which I compressed into a .ZIP folder and I had this ready.
I put everything on the website and had to edit everything manually, because unfortunately I had a stupid table. I also had to look for what parts to use for my components and that took me a lot of time.
So I chose a black PCB and then I dealt with installing 2 minimal PCBs!

sn__mek_obrazovky_2026-02-14_182733

So everything comes out to about 71 dollars, even with shipping. Which is very good, considering the previous price!
2/16/2026 - PicoFlip X
Time spent: 2.5h

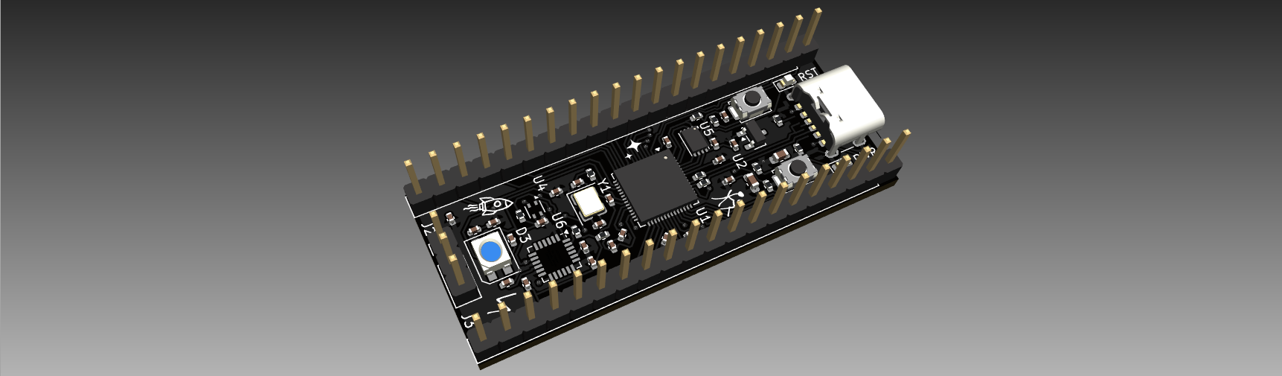
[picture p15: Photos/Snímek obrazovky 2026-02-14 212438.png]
header


PicoFlip X is a compact RP2040 development board with a built-in IMU for motion tracking, there's also a humidity and temperature sensor! It has several status LEDs, buttons,...

Key Features
DevBoard powered by RP2040 chip
Humidity and temperature sensor built right on the PCB
2 LEDs for visual feedback (PWR and RST)
IMU - MPU 6050 to monitor the board's current position, all built-in
USB-C connectivity
2-layer PCB, so it's cost-effective to manufacture!
Modified GPIO pin layout and added one extra +3V3
Custom silkscreen with images and descriptions
Why I made this project?
When I finished my last project, I was thinking again about what I could do... I thought I'd try something hard and test my nerves... 💀
So I was looking and came up with this project - DEVBOARD!!

Schema and PCB
Here is the circuit diagram!

Diagram

Next, here is the PCB that is created in KiCad:

PCB Design

The Design :)
Here is the top side of the PCB:

Diagram

Also here is the bottom of the PCB!



JLCPCB Order

 

Bill of Materials
Here is the complete BOM:
Top Designator	Comment	JLCPCB Part #	Product link	Lib Type	Qty	Source	Total Price ($)
C1,C10	1uF	C52923	Link	Basic	4	4 JLCPCB	0,0132
C2,C3,C4,C5,C6,C7,C8,C9,C11,C12,C17,C23	0.1uF	C1525	Link	Basic	32	32 JLCPCB	0,0416
C19,C21,C22,C24	100nF	↑	↑	↑	↑	↑	↑
C13,C14	10uF	C19702	Link	Basic	4	4 JLCPCB	0,026
C15,C16	33pF	C1562	Link	Basic	4	4 JLCPCB	0,0048
C18,C25	10nF	C60133	Link	Extended	20	20 JLCPCB	0,022
C20	2.2uF	C12530	Link	Basic	2	2 JLCPCB	0,0052
D3	SK6812MINI	C7423117	Link	Extended	5	5 JLCPCB	0,428
J1	USB_C_Receptacle_USB2.0_14P	C165948	Link	Extended	2	2 JLCPCB	0,3624
J2,J3	Conn_01x20	C50981	Link	Extended	4	4 JLCPCB	0,4812
J4	Conn_01x03	C49257	Link	Extended	4	4 JLCPCB	0,0692
PWR	POWER	C2286	Link	Basic	2	2 JLCPCB	0,0128
R1,R2	5.1K	C25905	Link	Basic	4	4 JLCPCB	0,0032
R3,R4	27	C25100	Link	Extended	20	20 JLCPCB	0,014
R5,R6,R7	1K	C11702	Link	Basic	6	6 JLCPCB	0,0042
R8,R9	4.7K	C25900	Link	Basic	4	4 JLCPCB	0,0032
R10	10K	C25744	Link	Basic	2	2 JLCPCB	0,0016
R11,R12	680	C25130	Link	Extended	20	20 JLCPCB	0,016
RST	RUN	C2288	Link	Extended	20	20 JLCPCB	0,198
SW1,SW2	SW_Push	C720477	Link	Basic	4	4 JLCPCB	0,1904
U1	RP2040	C2040	Link	Extended	2	2 JLCPCB	1,9318
U2	MCP1700x-330xxTT	C39051	Link	Extended	5	5 JLCPCB	1,807
U4	SHT4x	C2848306	Link	Extended	2	2 JLCPCB	3,427
U5	W25Q16JVZPIQTR	C2843335	Link	Extended	2	2 JLCPCB	2,3964
U6	MPU-6050	C24112	Link	Extended	2	2 JLCPCB	15,7754
Y1	12MHz	C9002	Link	Basic	2	2 JLCPCB	0,1452
PCBA (Parts + Assembly)							65,32
PCB (Black)							4
Shipping (GSDL)							1,5
TOTAL							70,82
The bill of material is also available here: BOM.csv
</details>
<hr>
> Made with ❤️ - by [@mavory](https://github.com/mavory) | Also thank you for providing the guide [@Kai Pereira](https://github.com/kaipereira)! 

3/28/2026 10:22 AM - The package has arrived!!!
Time spent: 0.5h
After a long time I can say that I was not so excited! After about 2 weeks I have the package from JLCPCB with me. I opened everything that day and everything looks very good!



I couldn't wait and went to try the DevBoard right away. I connected it and everything worked very well. I just had to change the USB driver to CDC via the Zadig application so that it would be recognized properly in the Thonny program/Arduino IDE.

Snímek obrazovky 2026-03-28 101224

Then it was a breeze and I was able to prepare my Board for soldering.
3/28/2026 10:48 AM - Soldering :)
Time spent: 0.7h
I decided to use colored DuPont headers and I think it looks pretty good!
So I started slowly soldering each part and after soldering the side headers I jumped on the debug header and chose yellow for it.

20260328_102939(0)

I should have finished it in less than half an hour and then I just cleaned the board and prepared it for testing with components.



3/28/2026 1 PM - Project completion
Time spent: 1.2h
Then I started working on the code, where I wanted to test the main things:
If the neopixel works at all
If the sensors send the correct data
If the GPIO works and if the text on the OLED display is displayed correctly
So I had the preparation ready and started writing the code. After a while I had it ready and decided that I would do it in Thonny. It was a completely new program for me, but I easily got used to it, so I appreciated that. I also added a print to the Serial monitor so I could watch it and also test if it works.



After a while I decided to run it and I must say that everything works PERFECTLY!



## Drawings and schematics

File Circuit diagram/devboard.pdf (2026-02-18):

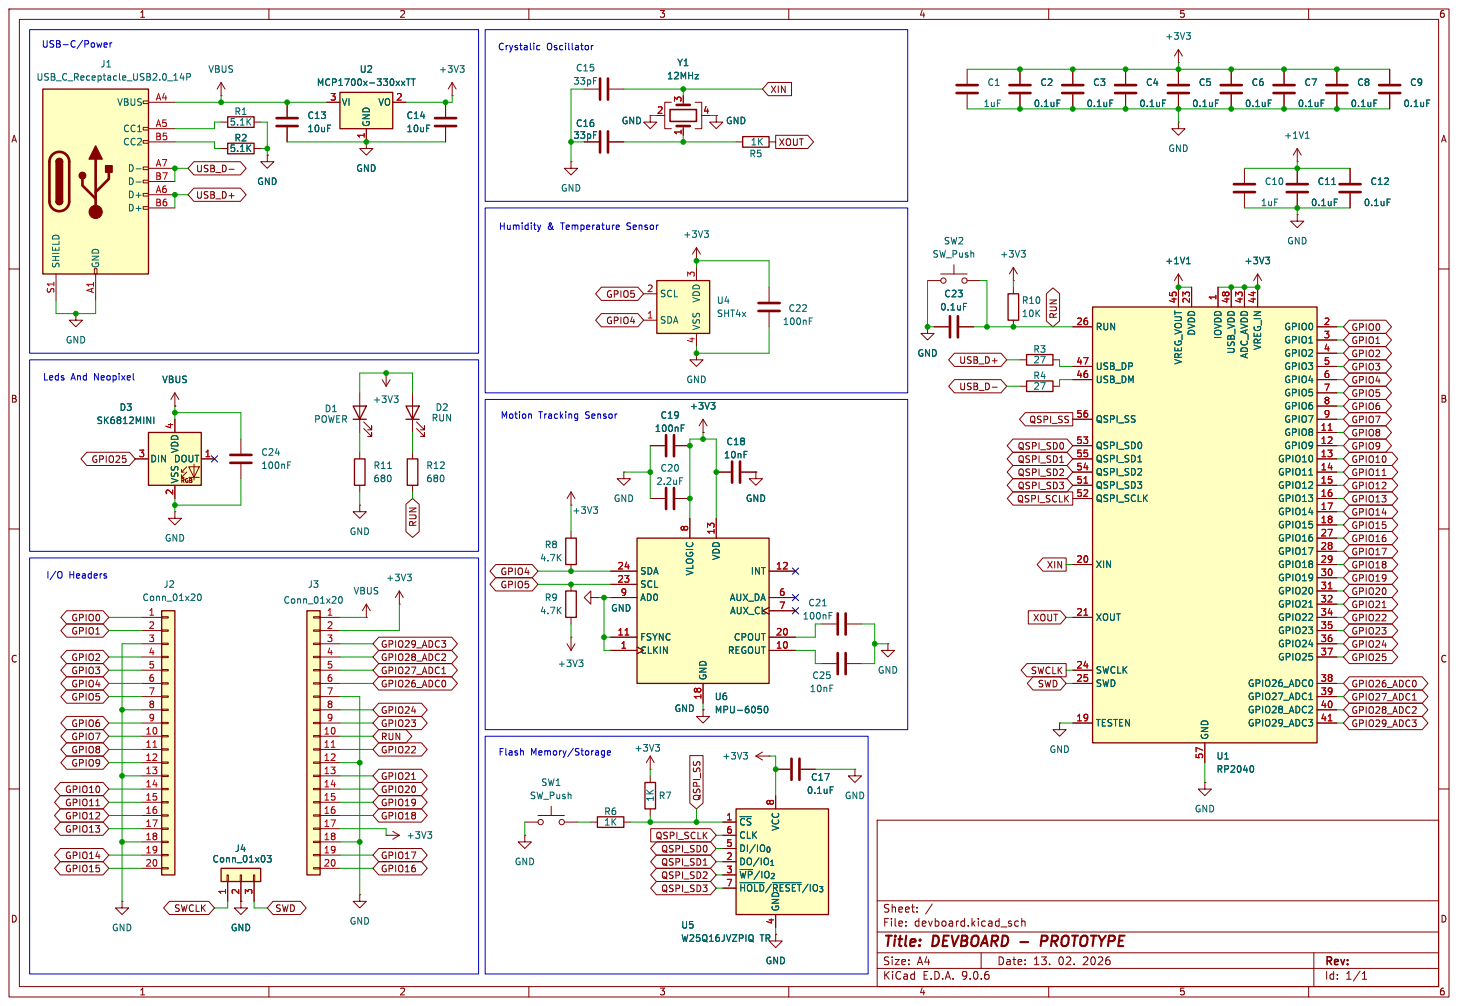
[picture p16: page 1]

Leds And Neopixel USB-C/Power
J1 USB_C_Receptacle_USB2.0_14P

1 VO 2 U2 MCP1700x-330xxTT GND GND GND

3 U6 MPU-6050 SDA 24 SCL 23 AD0 9 FSYNC 11 CLKIN 1 VLOGIC
0.1uF GND GND

File: devboard.kicad_sch Sheet: / GND

Id: 1/1 Title: DEVBOARD - PROTOTYPE

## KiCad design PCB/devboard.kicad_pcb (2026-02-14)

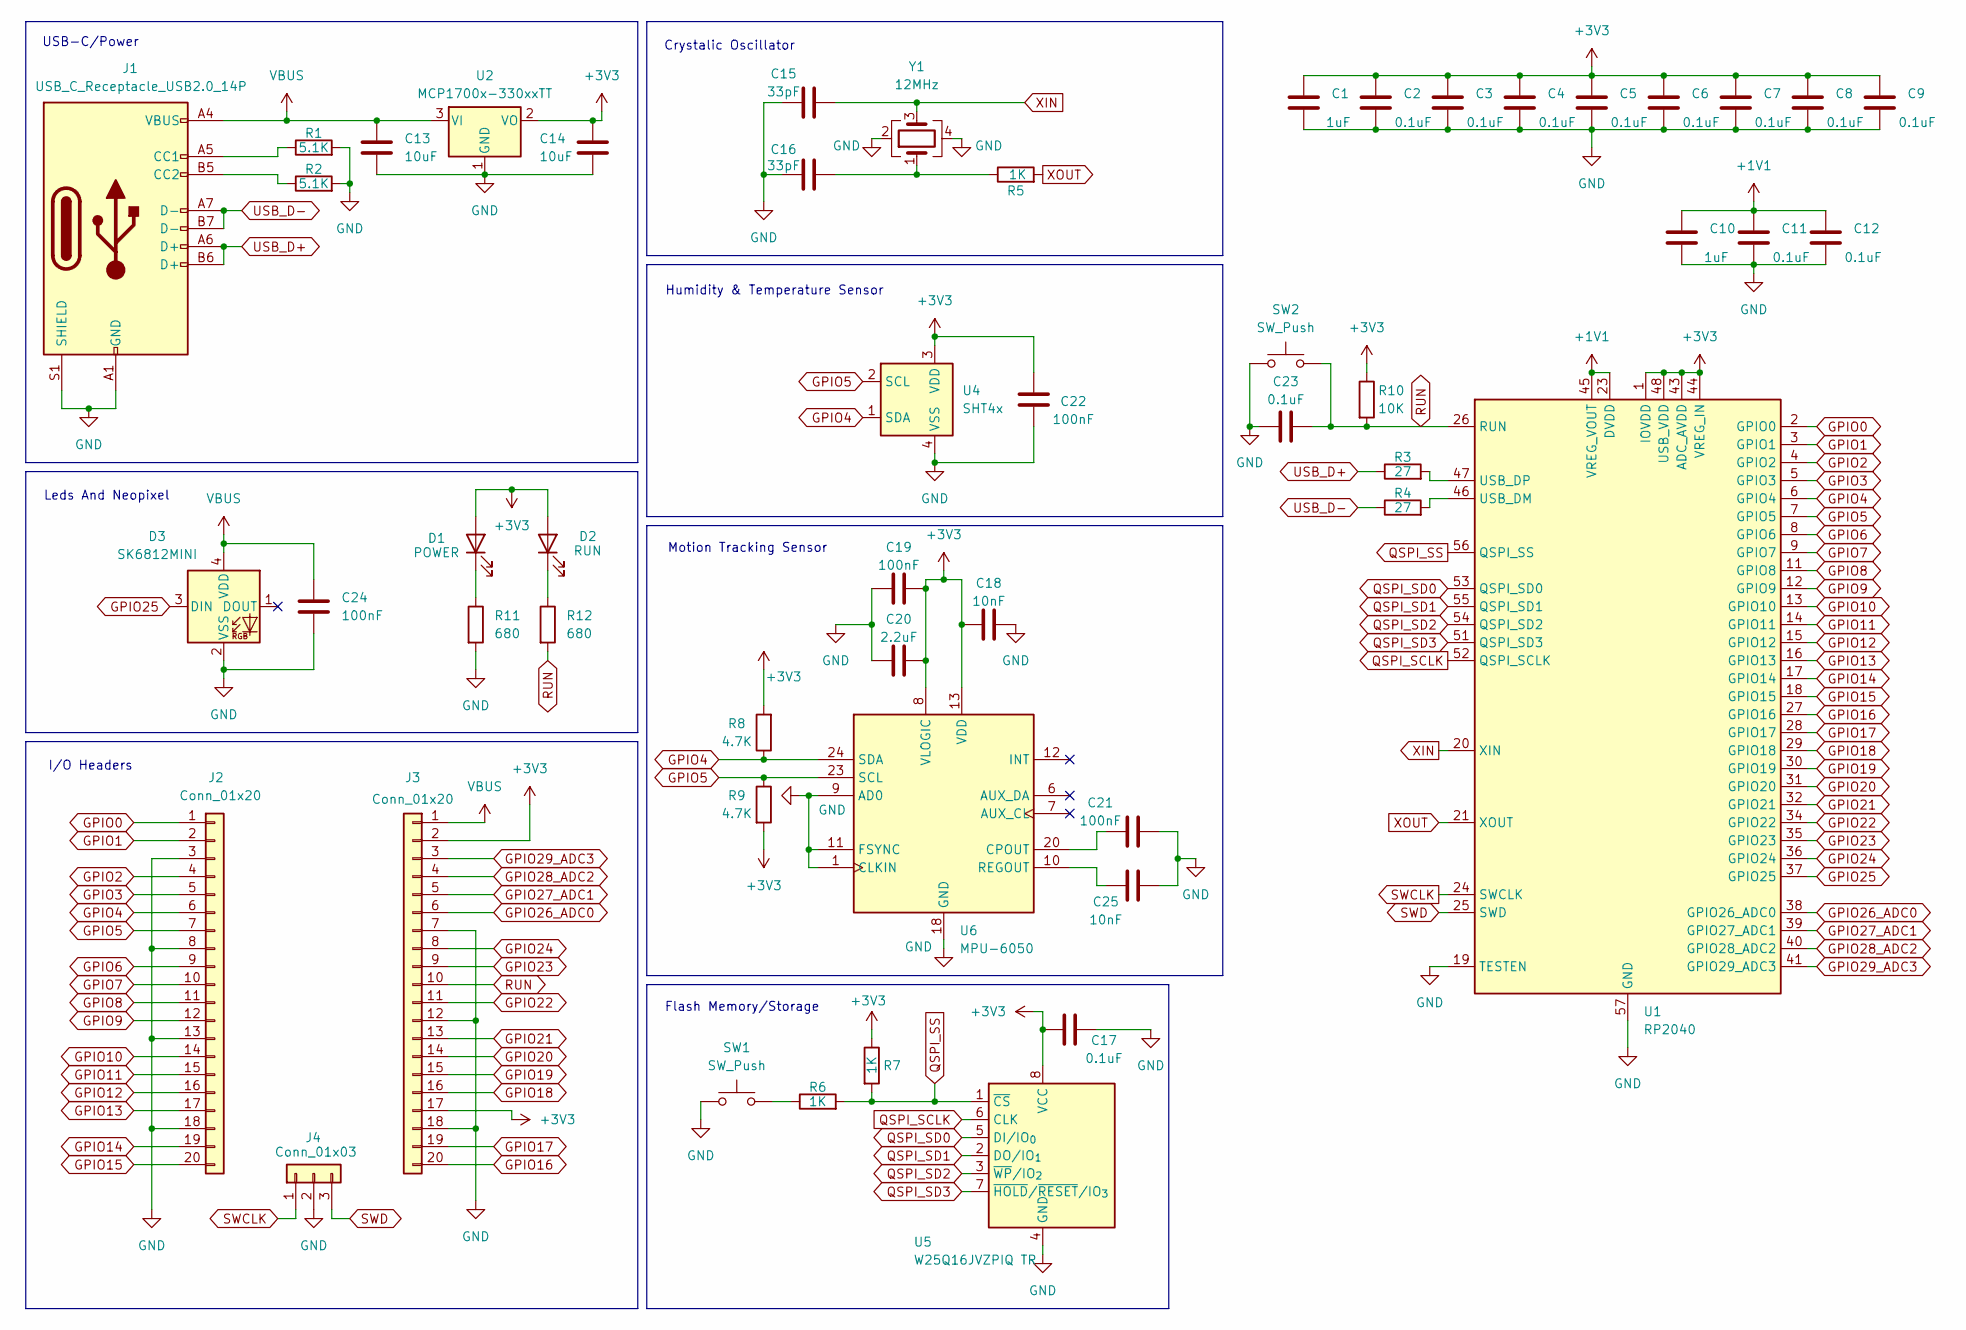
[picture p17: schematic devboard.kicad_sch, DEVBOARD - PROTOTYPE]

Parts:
C1, C10: 1uF; C_0402_1005Metric
C2, C3, C4, C5, C6, C7, C8, C9, C11, C12, C17, C23: 0.1uF; C_0402_1005Metric
C13, C14: 10uF; C_0603_1608Metric
C15, C16: 33pF; C_0402_1005Metric
C18, C25: 10nF; C_0402_1005Metric
C19, C21, C22, C24: 100nF; C_0402_1005Metric
C20: 2.2uF; C_0402_1005Metric
D1: POWER; LED_0603_1608Metric
D2: RUN; LED_0603_1608Metric
D3: SK6812MINI; LED_SK6812MINI_PLCC4_3.5x3.5mm_P1.75mm
J1: USB_C_Receptacle_USB2.0_14P; USB_C_Receptacle_HRO_TYPE-C-31-M-12
J2, J3: Conn_01x20; PinHeader_1x20_P2.54mm_Vertical
J4: Conn_01x03; PinHeader_1x03_P2.54mm_Vertical
R1, R2: 5.1K; R_0402_1005Metric
R3, R4: 27; R_0402_1005Metric
R5, R6, R7: 1K; R_0402_1005Metric
R8, R9: 4.7K; R_0402_1005Metric
R10: 10K; R_0402_1005Metric
R11, R12: 680; R_0402_1005Metric
SW1, SW2: SW_Push; SW_Push_SPST_NO_Alps_SKRK
U1: RP2040; QFN-56-1EP_7x7mm_P0.4mm_EP3.2x3.2mm
U2: MCP1700x-330xxTT; SOT-23
U4: SHT4x; Sensirion_DFN-4_1.5x1.5mm_P0.8mm_SHT4x_NoCentralPad
U5: W25Q16JVZPIQ TR; Winbond_USON-8-1EP_3x2mm_P0.5mm_EP0.2x1.6mm
U6: MPU-6050; InvenSense_QFN-24_4x4mm_P0.5mm
Y1: 12MHz; Crystal_SMD_3225-4Pin_3.2x2.5mm

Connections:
+1V1: C10.1, C11.1, C12.1, U1.23 (DVDD), U1.45 (VREG_VOUT), U1.50 (DVDD)
+3V3: C1.1, C2.1, C3.1, C4.1, C5.1, C6.1, C7.1, C8.1, C9.1, C14.1, C17.2, C18.1, C19.2, C20.2, C22.2, D1.2 (A), D2.2 (A), J3.2, J3.17, R7.1, R8.2, R9.2, R10.1, U1.1 (IOVDD), U1.10 (IOVDD), U1.22 (IOVDD), U1.33 (IOVDD), U1.42 (IOVDD), U1.43 (ADC_AVDD), U1.44 (VREG_IN), U1.48 (USB_VDD), U1.49 (IOVDD), U2.2 (VO), U4.3 (VDD), U5.8 (VCC), U6.8 (VLOGIC), U6.13 (VDD); also elsewhere on the board
GND: C1.2, C2.2, C3.2, C4.2, C5.2, C6.2, C7.2, C8.2, C9.2, C10.2, C11.2, C12.2, C13.2, C14.2, C15.1, C16.1, C17.1, C18.2, C19.1, C20.1, C21.2, C22.1, C23.1, C24.2, C25.2, D3.2 (VSS), J1.A1 (GND), J1.A12 (GND), J1.B1 (GND), J1.B12 (GND), J1.S1 (SHIELD), J2.3, J2.8, J2.13, J2.18, J3.7, J3.12, J3.18, J4.2, R1.2, R2.2, R11.2, SW1.1, SW2.1, U1.19 (TESTEN), U1.57 (GND), U2.1 (GND), U4.4 (VSS), U5.4 (GND), U6.1 (CLKIN), U6.9 (AD0), U6.11 (FSYNC), U6.18 (GND), Y1.2, Y1.4
GPIO0: J2.1, U1.2 (GPIO0)
GPIO1: J2.2, U1.3 (GPIO1)
GPIO2: J2.4, U1.4 (GPIO2)
GPIO3: J2.5, U1.5 (GPIO3)
GPIO4: J2.6, R8.1, U1.6 (GPIO4), U4.1 (SDA), U6.24 (SDA)
GPIO5: J2.7, R9.1, U1.7 (GPIO5), U4.2 (SCL), U6.23 (SCL)
GPIO6: J2.9, U1.8 (GPIO6)
GPIO7: J2.10, U1.9 (GPIO7)
GPIO8: J2.11, U1.11 (GPIO8)
GPIO9: J2.12, U1.12 (GPIO9)
GPIO10: J2.14, U1.13 (GPIO10)
GPIO11: J2.15, U1.14 (GPIO11)
GPIO12: J2.16, U1.15 (GPIO12)
GPIO13: J2.17, U1.16 (GPIO13)
GPIO14: J2.19, U1.17 (GPIO14)
GPIO15: J2.20, U1.18 (GPIO15)
GPIO16: J3.20, U1.27 (GPIO16)
GPIO17: J3.19, U1.28 (GPIO17)
GPIO18: J3.16, U1.29 (GPIO18)
GPIO19: J3.15, U1.30 (GPIO19)
GPIO20: J3.14, U1.31 (GPIO20)
GPIO21: J3.13, U1.32 (GPIO21)
GPIO22: J3.11, U1.34 (GPIO22)
GPIO23: J3.9, U1.35 (GPIO23)
GPIO24: J3.8, U1.36 (GPIO24)
GPIO25: D3.3 (DIN), U1.37 (GPIO25)
GPIO26_ADC0: J3.6, U1.38 (GPIO26_ADC0)
GPIO27_ADC1: J3.5, U1.39 (GPIO27_ADC1)
GPIO28_ADC2: J3.4, U1.40 (GPIO28_ADC2)
GPIO29_ADC3: J3.3, U1.41 (GPIO29_ADC3)
unnamed: C16.2, R5.1, Y1.1
unnamed 34: D1.1 (K), R11.1; also elsewhere on the board
unnamed 35: D2.1 (K), R12.1; also elsewhere on the board
unnamed: J1.A5 (CC1), R1.1
unnamed: J1.B5 (CC2), R2.1
unnamed: R6.1, SW1.2
unnamed: R4.2, U1.46 (USB_DM)
unnamed: R3.2, U1.47 (USB_DP)
unnamed: C21.1, U6.20 (CPOUT)
unnamed: C25.1, U6.10 (REGOUT)
QSPI_SCLK: U1.52 (QSPI_SCLK), U5.6 (CLK)
QSPI_SD0: U1.53 (QSPI_SD0), U5.5 (DI/IO_{0})
QSPI_SD1: U1.55 (QSPI_SD1), U5.2 (DO/IO_{1})
QSPI_SD2: U1.54 (QSPI_SD2), U5.3 (~WP/IO_{2})
QSPI_SD3: U1.51 (QSPI_SD3), U5.7 (~HOLD/~RESET/IO_{3})
QSPI_SS: R6.2, R7.2, U1.56 (QSPI_SS), U5.1 (~CS)
RUN: C23.2, J3.10, R10.2, R12.2, SW2.2, U1.26 (RUN)
SWCLK: J4.1, U1.24 (SWCLK)
SWD: J4.3, U1.25 (SWD)
USB_D+: J1.A6 (D+), J1.B6 (D+), R3.1
USB_D-: J1.A7 (D-), J1.B7 (D-), R4.1
VBUS: C13.1, C24.1, D3.4 (VDD), J1.A4 (VBUS), J1.A9 (VBUS), J1.B4 (VBUS), J1.B9 (VBUS), J3.1, U2.3 (VI)
XIN: C15.2, U1.20 (XIN), Y1.3
XOUT: R5.2, U1.21 (XOUT)

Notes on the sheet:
Leds And Neopixel
Flash Memory/Storage
Crystalic Oscillator
Motion Tracking Sensor
Humidity & Temperature Sensor
USB-C/Power
I/O Headers

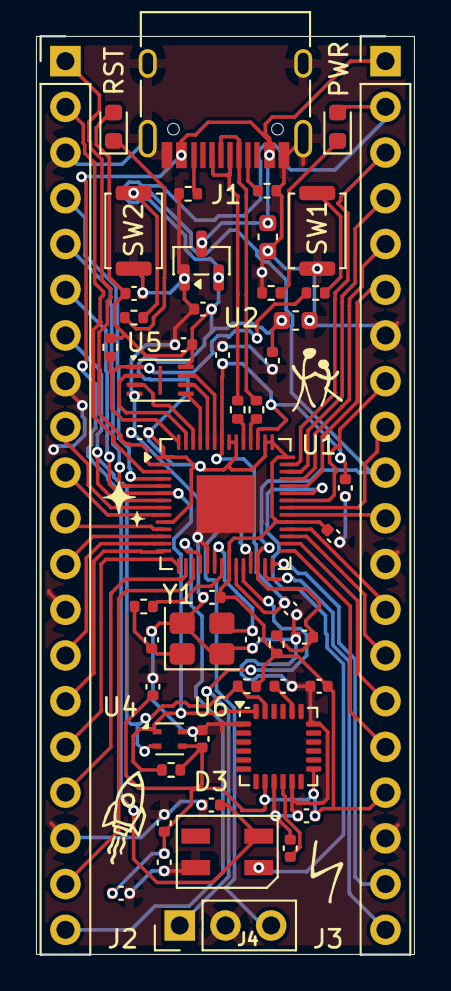
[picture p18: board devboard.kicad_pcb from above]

Board: 2 copper layers, 21.0 x 51.0 mm, 52 parts (0 on the bottom side), 57 nets.

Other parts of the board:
PWR: POWER; LED_0603_1608Metric
RST: RUN; LED_0603_1608Metric

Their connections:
+3V3: PWR.2 (A), RST.2 (A); also elsewhere on the board
unnamed 34: PWR.1 (K); also elsewhere on the board
unnamed 35: RST.1 (K); also elsewhere on the board

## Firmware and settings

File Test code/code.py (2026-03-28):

import machine, neopixel, time, ssd1306

NEOPIXEL_PIN = 25
LED_EXTERNAL_PIN = 16
SDA_PIN = 4
SCL_PIN = 5
OLED_WIDTH = 128
OLED_HEIGHT = 64
OLED_I2C_ADDR = 0x3C 

i2c = machine.I2C(0, sda=machine.Pin(SDA_PIN), scl=machine.Pin(SCL_PIN))

led_ext = machine.Pin(LED_EXTERNAL_PIN, machine.Pin.OUT)
try:
    # 8mA
    led_ext.init(machine.Pin.OUT, drive=2)
except:
    pass 

pixel = neopixel.NeoPixel(machine.Pin(NEOPIXEL_PIN), 1)

# OLED 
try:
    oled = ssd1306.SSD1306_I2C(OLED_WIDTH, OLED_HEIGHT, i2c, addr=OLED_I2C_ADDR)
except:
    oled = None

def init_mpu():
    try: i2c.writeto_mem(0x68, 0x6B, b'\x00')
    except: pass

def get_mpu_pos():
    def read_w(reg):
        try:
            h = i2c.readfrom_mem(0x68, reg, 1)[0]
            l = i2c.readfrom_mem(0x68, reg+1, 1)[0]
            v = (h << 8) | l
            return v - 65536 if v > 32767 else v
        except: return 0
    ax, ay, az = read_w(0x3B), read_w(0x3D), read_w(0x3F)
    limit = 8000
    if az < -8000: return "UPSIDE DOWN"
    if ay > limit: return "TILT FRONT"
    if ay < -limit: return "TILT BACK"
    if ax > limit: return "SIDE LEFT"
    if ax < -limit: return "SIDE RIGHT"
    return "LEVEL"

def get_sht():
    try:
        i2c.writeto(0x44, b'\xFD')
        time.sleep(0.01)
        d = i2c.readfrom(0x44, 6)
        return -45 + 175 * (d[0]<<8|d[1])/65535, -6 + 125 * (d[3]<<8|d[4])/65535
    except: return None, None

def hsv_to_rgb(h, s, v):
    i = int(h*6); f = h*6-i; p, q, t = v*(1-s), v*(1-s*f), v*(1-s*(1-f))
    i %= 6
    if i==0: return v,t,p
    if i==1: return v,q,p
    if i==2: return p,v,t
    if i==3: return p,v,q
    if i==4: return t,p,v
    return v,p,q

# maiiin
init_mpu()
hue = 0.0
last_blink = time.ticks_ms()
last_print = time.ticks_ms()

print("PicoFlip X: English firmware online.")

while True:
    now = time.ticks_ms()
    
    # NeoPixel 
    r, g, b = hsv_to_rgb(hue, 1.0, 0.1)
    pixel[0] = (int(r*255), int(g*255), int(b*255))
    pixel.write()
    hue = (hue + 0.002) % 1.0 
    
    # LED 
    if time.ticks_diff(now, last_blink) >= 1000:
        led_ext.value(not led_ext.value())
        last_blink = now
        
    # Data
    if time.ticks_diff(now, last_print) >= 500:
        temp, humi = get_sht()
        pos = get_mpu_pos()
        
        if oled:
            oled.fill(0)
            oled.text("--- PICOFLIP X ---", 0, 0)
            oled.text(f"Temp: {temp:.1f} C" if temp else "Temp: Error", 0, 20)
            oled.text(f"Humi: {humi:.1f} %" if humi else "Humi: Error", 0, 32)
            oled.text(f"Pos: {pos}", 0, 50)
            oled.show()
        
        # Serial monitor pro Thonny
        t_str = f"{temp:.1f}C" if temp else "Err"
        h_str = f"{humi:.1f}%" if humi else "Err"
        print(f"[{t_str} | {h_str}] Orientation: {pos}")
        
        last_print = now
    
    time.sleep(0.02)

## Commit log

2026-02-14 Printed Circuit Board
    [3D model.step, devboard.kicad_pcb]
2026-02-14 Bill of Materials
    [BOM.csv]
2026-02-14 Update BOM.csv with shipping details
    Added shipping information and ensured proper formatting.
    [BOM.csv]
2026-02-15 Update BOM.csv with new components and prices
    [BOM.csv]
2026-02-15 Update BOM.csv with new component entries
    [BOM.csv]
2026-02-16 New prices
    [BOM.csv]
2026-02-16 Revise BOM format to include quantities
    Updated BOM to include quantity for each component and adjusted formatting.
    [BOM.csv]
2026-02-16 Revise BOM.csv for component details and pricing
    Updated component names and prices in BOM.
    [BOM.csv]
2026-02-16 Convert BOM.csv to standard CSV format
    Updated BOM.csv to use CSV format with headers and values.
    [BOM.csv]
2026-02-16 Fix BOM.csv formatting and restore header
    [BOM.csv]
2026-02-16 Update BOM.csv with new part details and links
    [BOM.csv]
2026-02-16 Update BOM.csv with new parts and pricing
    [BOM.csv]
2026-02-16 Update BOM.csv with new components and formatting
    The BOM.csv file was updated to include new entries and correct formatting issues.
    [BOM.csv]
2026-02-18 New files!
    [devboard-B_Cu.gbr, devboard-B_Mask.gbr, devboard-B_Paste.gbr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]
2026-02-18 PCB files
    [devboard-B_Cu.gbr, devboard-B_Mask.gbr, devboard-B_Paste.gbr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]
